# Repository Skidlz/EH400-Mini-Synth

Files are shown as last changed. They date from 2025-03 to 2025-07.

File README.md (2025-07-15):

# EH400-Mini-Synth
A recreation of the EH400 Mini-Synthesizer from Electro Harmonix.
Includes Eagle CAD files, and gerbers
 
 #### PCB Renders ####
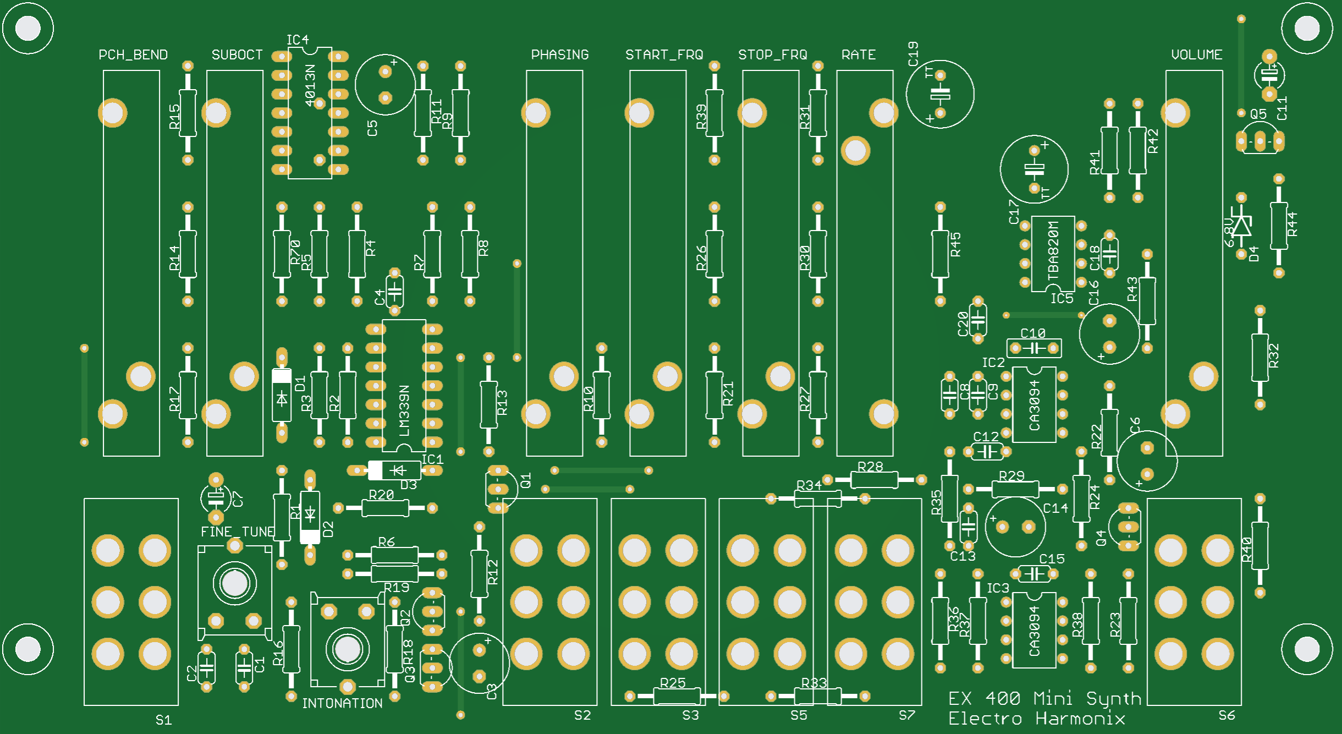
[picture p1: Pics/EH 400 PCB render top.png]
PCB Top
 
 
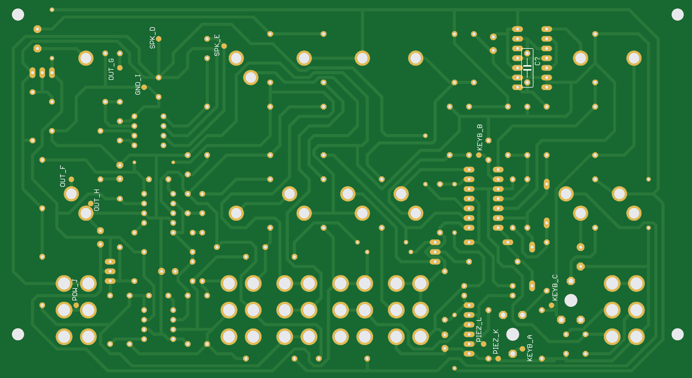
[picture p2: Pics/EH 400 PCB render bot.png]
PCB Bottom
 

 #### Schematic ####
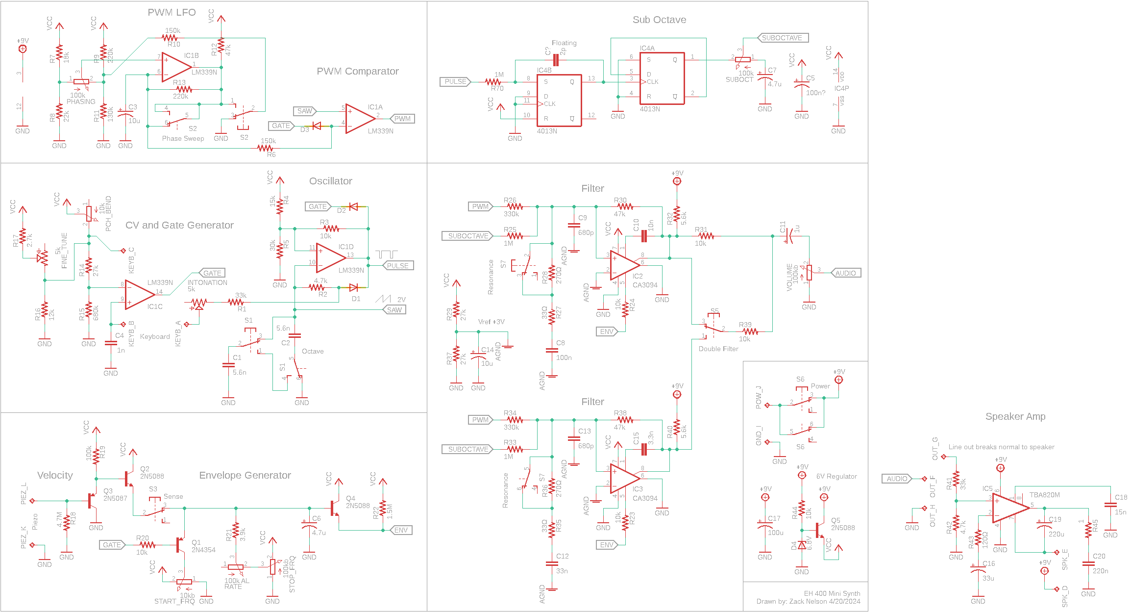
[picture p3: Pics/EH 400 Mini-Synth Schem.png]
Schematic
 

 #### Board ####
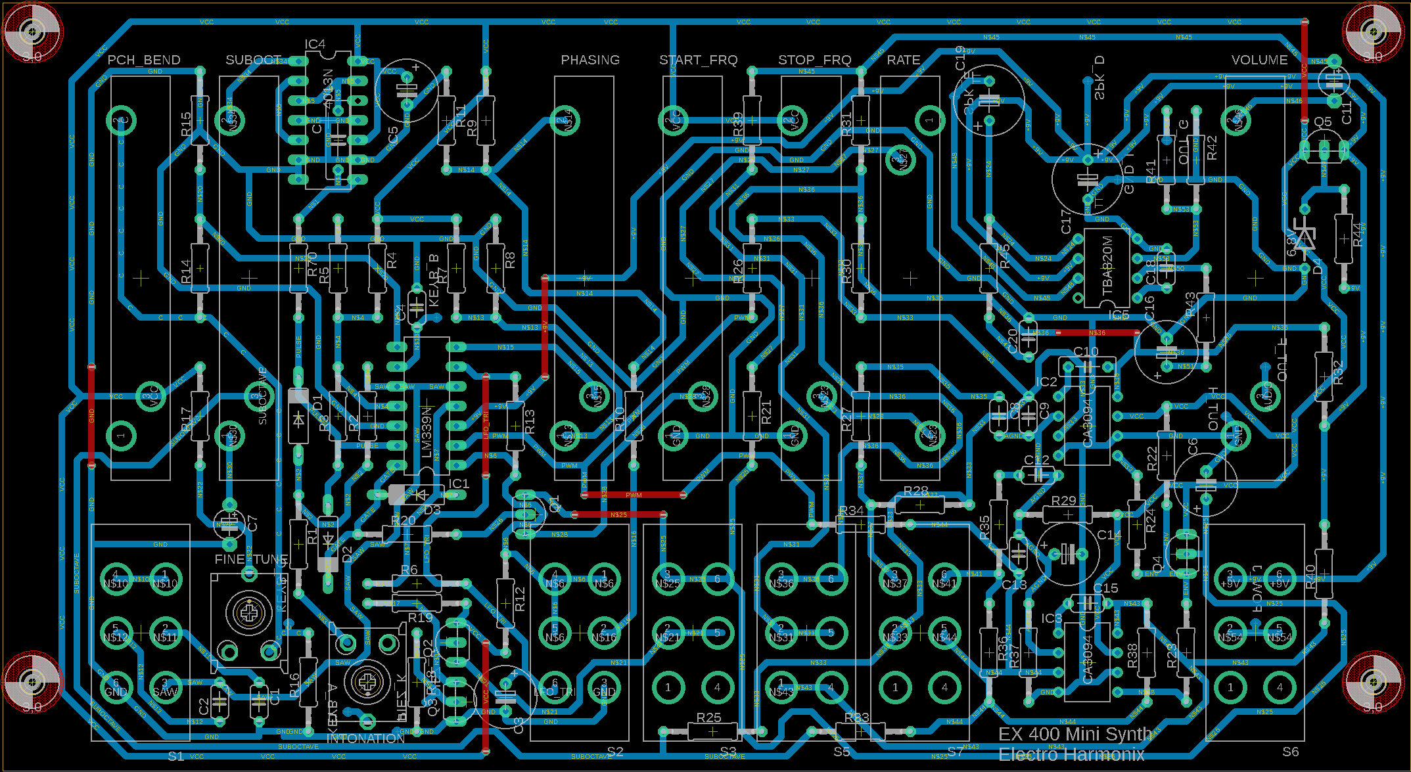
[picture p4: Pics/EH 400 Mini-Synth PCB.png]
Board


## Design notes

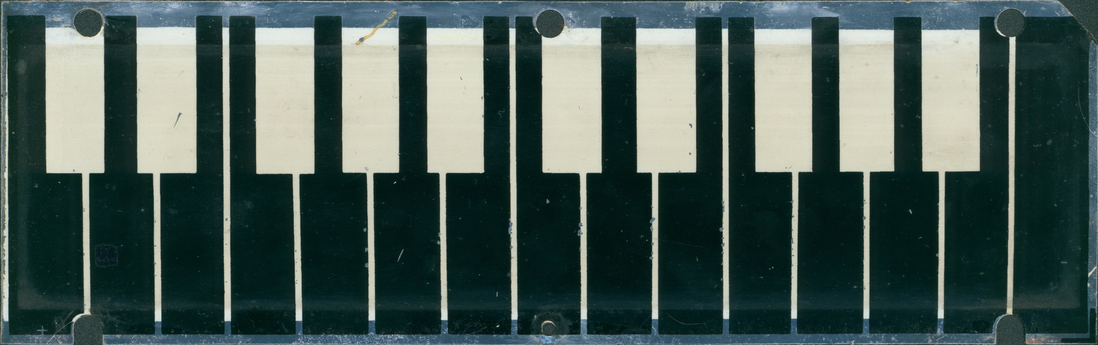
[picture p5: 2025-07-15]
Pics/EH400 Keyfoil top.jpg

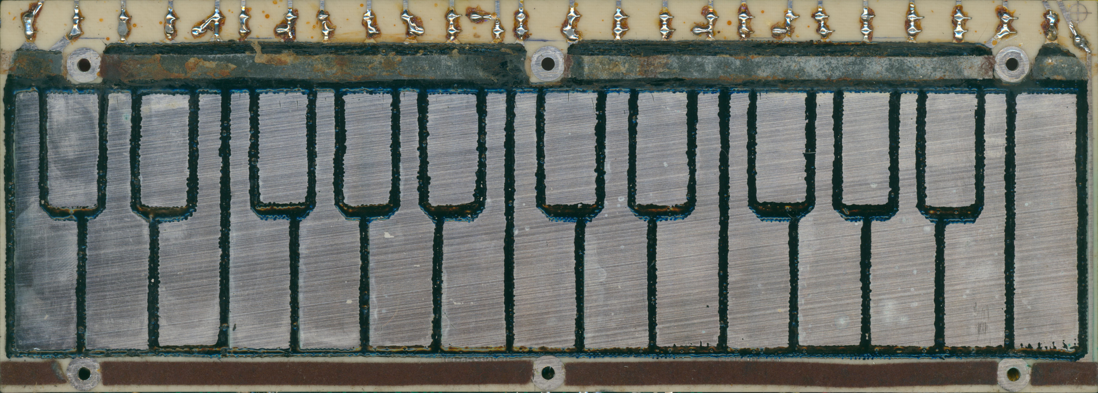
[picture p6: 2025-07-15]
Pics/EH400 Key board.jpg

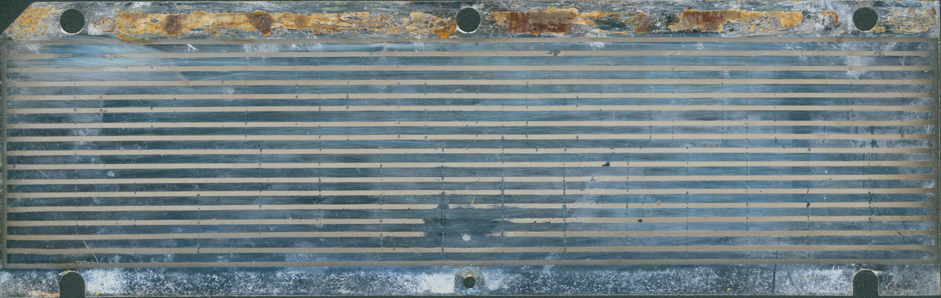
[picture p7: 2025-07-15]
Pics/EH400 Keyfoil bot.jpg

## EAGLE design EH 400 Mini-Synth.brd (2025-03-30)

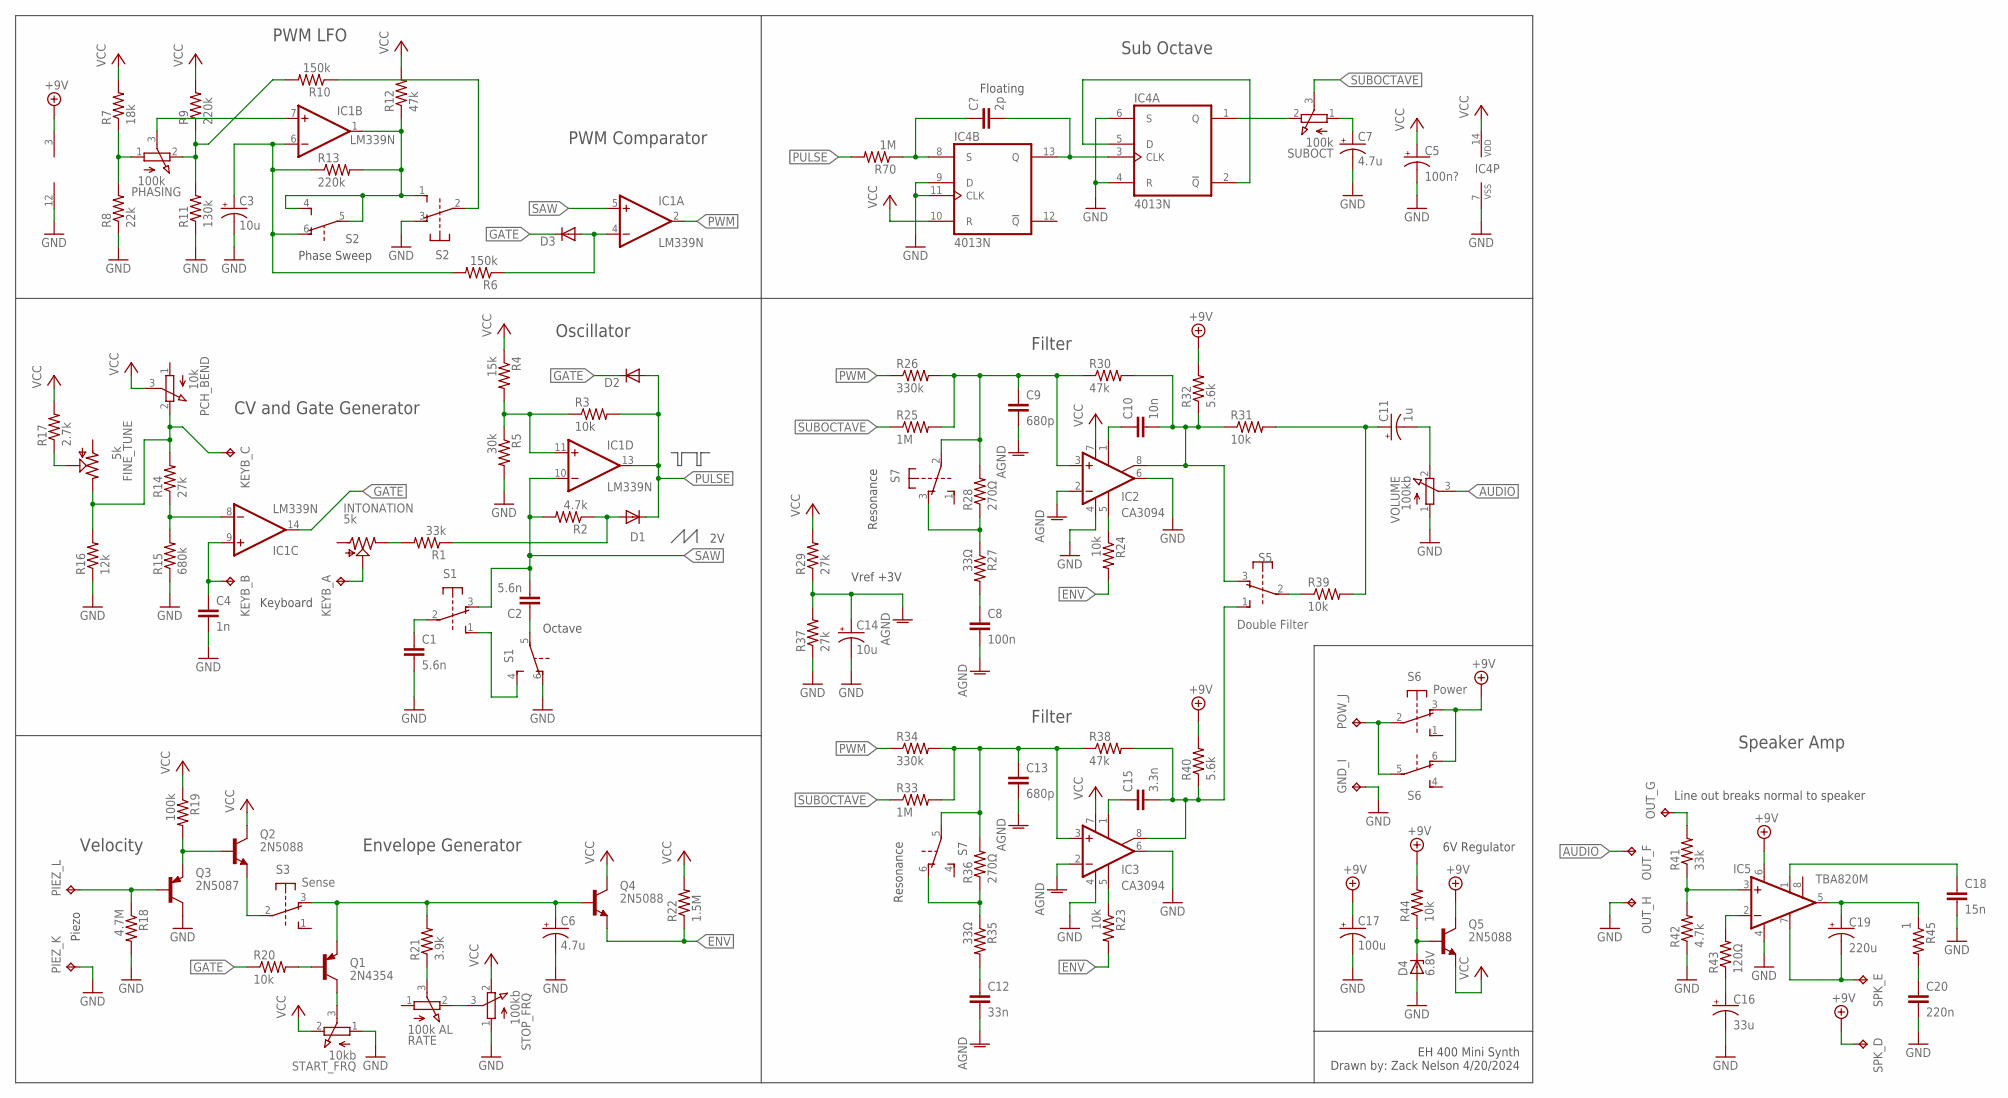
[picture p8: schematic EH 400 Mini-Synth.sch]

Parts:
C1, C2: 5.6n; C050-024X044
C3, C14: 10u; E3,5-8
C4: 1n; C050-024X044
C5: 100n?; E3,5-8
C6: 4.7u; E3,5-8
C7: 4.7u; E5-4
C8: 100n; C050-024X044
C9, C13: 680p; C050-024X044
C10: 10n; C050-025X075
C11: 1u; E5-4
C12: 33n; C050-024X044
C15: 3.3n; C050-024X044
C16: 33u; E3,5-8
C17: 100u; TT5D9
C18: 15n; C050-024X044
C19: 220u; TT5D9
C20: 220n; C050-024X044
C?: 2p; C075-032X103
D1, D2, D3: DIODE-DO07; DO07
D4: 6.8V; ZDIO-7.5
FINE_TUNE: 5k; ECP10S
GND_I: TPB1,27; B1,27
IC1: LM339N; DIL14
IC2, IC3: CA3094; DIL08
IC4: 4013N; DIL14
IC5: TBA820M; DIL08
INTONATION: 5k; ECP10S
KEYB_A: TPB1,27; B1,27
KEYB_B: TPB1,27; B1,27
KEYB_C: TPB1,27; B1,27
OUT_F: TPB1,27; B1,27
OUT_G: TPB1,27; B1,27
OUT_H: TPB1,27; B1,27
PCH_BEND: 10k; FADER-EHX
PHASING: 100k; FADER-EHX
PIEZ_K: TPB1,27; B1,27
PIEZ_L: TPB1,27; B1,27
POW_J: TPB1,27; B1,27
Q1: 2N4354; TO92-EBC
Q2, Q4, Q5: 2N5088; TO92-EBC
Q3: 2N5087; TO92-EBC
R1, R41: 33k; 0207/12
R2, R42: 4.7k; 0207/12
R3, R20, R23, R24, R31, R39, R44: 10k; 0207/12
R4: 15k; 0207/12
R5: 30k; 0207/12
R6, R10: 150k; 0207/12
R7: 18k; 0207/12
R8: 22k; 0207/12
R9, R13: 220k; 0207/12
R11: 130k; 0207/12
R12, R30, R38: 47k; 0207/12
R14, R29, R37: 27k; 0207/12
R15: 680k; 0207/12
R16: 12k; 0207/12
R17: 2.7k; 0207/12
R18: 4.7M; 0207/12
R19: 100k; 0207/12
R21: 3.9k; 0207/12
R22: 1.5M; 0207/12
R25, R33, R70: 1M; 0207/12
R26, R34: 330k; 0207/12
R27, R35: 33Ω; 0207/12
R28, R36: 270Ω; 0207/12
R32, R40: 5.6k; 0207/12
R43: 120Ω; 0207/12
R45: 1; 0207/12
RATE: 100k AL; FADER-EHX
S1: Octave; SLIDE
S2: Phase; SLIDE
S3: Sense; SLIDE
S5: Double Filter; SLIDE
S6: Power; SLIDE
S7: 9077-2S; SLIDE
SPK_D: TPB1,27; B1,27
SPK_E: TPB1,27; B1,27
START_FRQ: 10kb; FADER-EHX
STOP_FRQ: 100kb; FADER-EHX
SUBOCT: 100k; FADER-EHX
VOLUME: 100kb; FADER-EHX

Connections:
+9V: C17.+, IC1.3 (V+), IC5.6 (VS), Q5.C, R32.2, R40.2, R44.2, S6.3 (O), S6.6 (O), SPK_D.TP
AGND: C8.2, C9.2, C12.2, C13.2, C14.+, IC2.2 (-IN), IC3.2 (-IN), R29.1, R37.2
AUDIO: OUT_F.TP, VOLUME.3 (S)
C: FINE_TUNE.E, KEYB_C.TP, PCH_BEND.2 (E), R14.2, R16.2
ENV: Q4.E, R22.1, R23.2, R24.2
GATE: D2.C, D3.C, IC1.14 (OUT), R20.1
GND: C1.2, C3.-, C4.2, C5.-, C6.-, C7.-, C14.-, C16.-, C17.-, C18.2, C20.2, D4.A, GND_I.TP, IC1.12 (GND), IC2.4 (V-), IC2.6 (OUT), IC3.4 (V-), IC3.6 (OUT), IC4.4 (R), IC4.6 (S), IC4.7 (VSS), IC4.9 (D), IC4.11 (CLK), IC5.4 (GND), OUT_H.TP, PIEZ_K.TP, Q3.C, R5.2, R8.1, R11.1, R15.1, R16.1, R18.2, R37.1, R42.1, S1.6 (O), S2.3 (O), START_FRQ.1 (A), STOP_FRQ.1 (A), VOLUME.1 (A)
LFO_TRI: C3.+, IC1.6 (-IN), R6.2, R13.1, S2.6 (O)
unnamed: C?.1, IC4.8 (S), R70.1
unnamed: D1.A, R1.1, R2.1
unnamed: INTONATION.E, R1.2
unnamed: IC1.11 (+IN), R3.1, R4.2, R5.1
unnamed: C?.2, IC4.3 (CLK), IC4.13 (Q)
unnamed: IC1.1 (OUT), R12.1, R13.2, S2.1 (S), S2.4 (S), S2.5
unnamed: D3.A, IC1.4 (-IN), R6.1
unnamed: IC4.2 (!Q), IC4.5 (D)
unnamed: PIEZ_L.TP, Q3.B, R18.1
unnamed: S1.1 (S), S1.4 (S)
unnamed: C1.1, S1.2
unnamed: C2.1, S1.5
unnamed: PHASING.1 (A), R7.1, R8.2
unnamed: PHASING.2 (E), R9.1, R10.2, R11.2
unnamed: IC1.7 (+IN), PHASING.3 (S)
unnamed: R10.1, S2.2
unnamed: Q2.B, Q3.E, R19.2
unnamed: C4.1, IC1.9 (+IN), KEYB_B.TP
unnamed: INTONATION.S, KEYB_A.TP
unnamed: IC1.8 (-IN), R14.1, R15.2
unnamed: Q2.E, S3.2
unnamed: FINE_TUNE.S, R17.1
unnamed: RATE.2 (E), STOP_FRQ.3 (S)
unnamed: C19.+, IC5.5 (OUT), R45.1
unnamed: C6.+, Q1.E, Q4.B, R21.2, S3.3 (O)
unnamed: Q1.B, R20.2
unnamed: R21.1, RATE.3 (S)
unnamed: Q1.C, START_FRQ.3 (S)
unnamed: C18.1, IC5.1 (GAIN)
unnamed: C7.+, SUBOCT.1 (A)
unnamed: R39.1, S5.2
unnamed: IC2.5 (OPT), R24.1
unnamed: C9.1, IC2.3 (+IN), R25.2, R26.2, R28.2, R30.1, S7.2
unnamed: IC4.1 (Q), SUBOCT.2 (E)
unnamed: C8.1, R27.2
unnamed: C10.2, IC2.8 (ON2), R30.2, R31.1, R32.1, S5.3 (O)
unnamed: R27.1, R28.1, S7.3 (O)
unnamed: IC3.5 (OPT), R23.1
unnamed: C10.1, IC2.1 (ON1)
unnamed: C12.1, R35.2
unnamed: R35.1, R36.1, S7.6 (O)
unnamed: C15.1, IC3.1 (ON1)
unnamed: C15.2, IC3.8 (ON2), R38.2, R40.1, S5.1 (S)
unnamed: C13.1, IC3.3 (+IN), R33.2, R34.2, R36.2, R38.1, S7.5
unnamed: C11.+, R31.2, R39.2
unnamed: C11.-, VOLUME.2 (E)
unnamed: C20.1, R45.2
unnamed: C19.-, IC5.7 (BYPASS), SPK_E.TP
unnamed: D4.C, Q5.B, R44.1
unnamed: IC5.2 (-IN), R43.2
unnamed: C16.+, R43.1
unnamed: OUT_G.TP, R41.2
unnamed: IC5.3 (+IN), R41.1, R42.2
unnamed: POW_J.TP, S6.2, S6.5
PULSE: D1.C, D2.A, IC1.13 (OUT), R3.2, R70.2
PWM: IC1.2 (OUT), R26.1, R34.1
SAW: C2.2, IC1.5 (+IN), IC1.10 (-IN), R2.2, S1.3 (O)
SUBOCTAVE: R25.1, R33.1, SUBOCT.3 (S)
VCC: C5.+, IC2.7 (V+), IC3.7 (V+), IC4.10 (R), IC4.14 (VDD), PCH_BEND.3 (S), Q2.C, Q4.C, Q5.E, R4.1, R7.2, R9.2, R12.2, R17.2, R19.1, R22.2, R29.2, START_FRQ.2 (E), STOP_FRQ.2 (E)

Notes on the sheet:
Phase Sweep
Octave
Oscillator
CV and Gate Generator
PWM LFO
PWM Comparator
Envelope Generator
6V Regulator
EH 400 Mini Synth Drawn by: Zack Nelson 4/20/2024
Vref +3V
Velocity
Filter
Resonance
Sub Octave
Floating
Line out breaks normal to speaker
Piezo
Keyboard
Speaker Amp

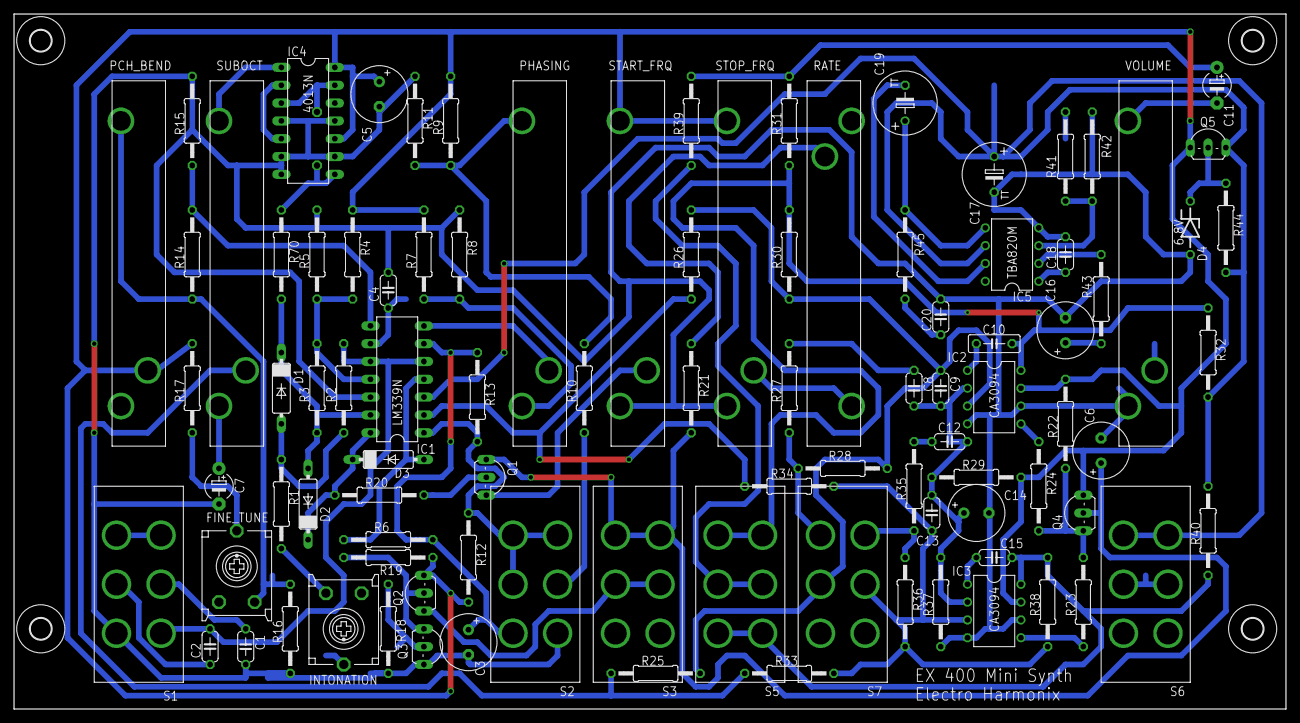
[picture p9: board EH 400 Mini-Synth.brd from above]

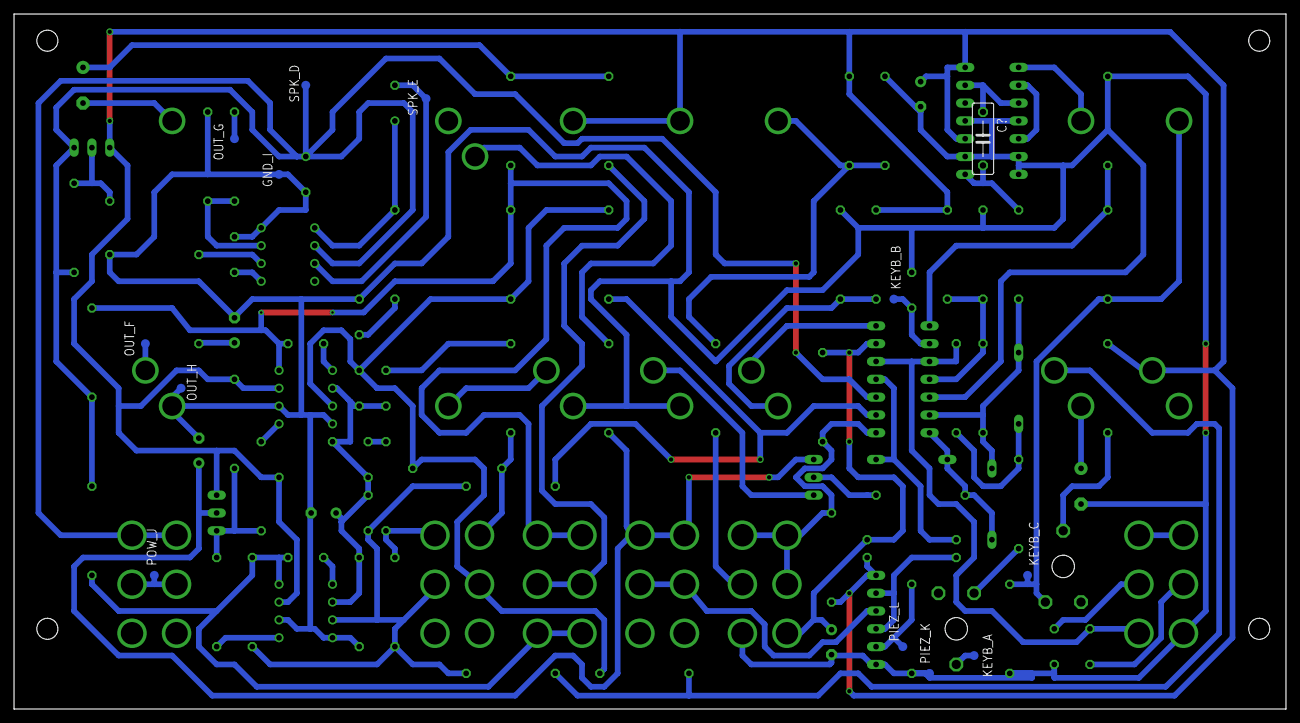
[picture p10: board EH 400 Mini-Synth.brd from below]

Board: 2 copper layers, 181.3 x 99.0 mm, 112 parts (13 on the bottom side), 67 nets.

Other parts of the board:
U$1, U$2, U$3, U$4: 3,0
